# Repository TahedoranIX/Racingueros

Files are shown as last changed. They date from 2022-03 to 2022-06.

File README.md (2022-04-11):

# Racingueros
Todos los proyectos que vayamos haciendo a los coches.

## Proyectos
### [CuentaRevoluciones](https://github.com/TahedoranIX/Racingueros/tree/main/CuentaRevoluciones)
Cuentarevoluciones hecho con RPi zero W con pantalla lcd 16x2 y funciona mediante OBD.

## Estado de Proyectos
### Ideas

### En proceso

### Acabado
   **CuentaRevoluciones**

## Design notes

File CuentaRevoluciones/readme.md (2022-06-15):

# CuentaRevoluciones
Cuentarrevoluciones hecho con RPi zero W con pantalla lcd 16x2 y rotary-encoder. Funciona mediante OBDII.

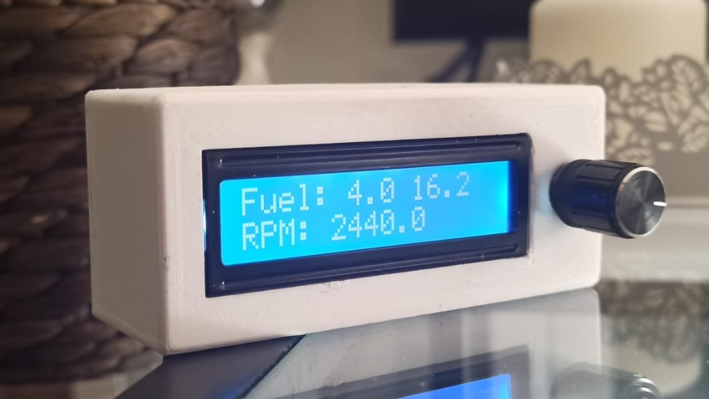
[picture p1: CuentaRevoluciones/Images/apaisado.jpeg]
CRR


### Objetivos
Mi Smart Fortwo solo tiene cuentarrevoluciones si lo pagas como un extra, el mío no vino con ese extra y no me apetece pagar más por él así que decidí hacerme uno utilizando el protocolo
 OBD-II.
La idea inicial es solo mostrar las revoluciones del motor pero como veréis, he implementado más cosas.
 
### Qué es? Cómo funciona?

Todo el programa esta escrito en Python3 y ejecutado en una RaspberryPi Zero W (versión con WiFi y Bluetooth).

La conexión al puerto OBD se realiza mediante Bluetooth y la librería python-OBD.

La pantalla utilizada es la típica LCD de 16x2 píxeles y adicionalmente utiliza un Rotary encoder para poder navegar entre distintos menús.

### Funciones Actuales
Actualmente el programa puede mostrar:
- RPM del motor.
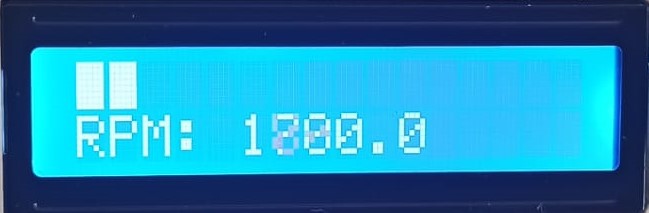
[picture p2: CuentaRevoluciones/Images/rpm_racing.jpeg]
RPM


- Temperatura del Refrigerante.
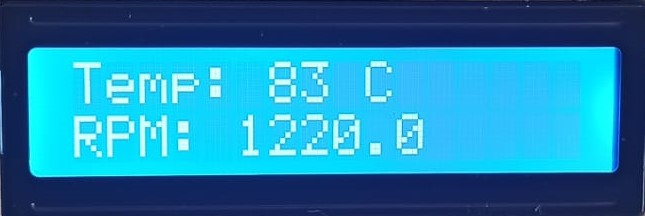
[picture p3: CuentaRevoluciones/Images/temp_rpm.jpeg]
Coolant Temp


- Consumo de gasolina (aproximado gracias al sensor MAF).
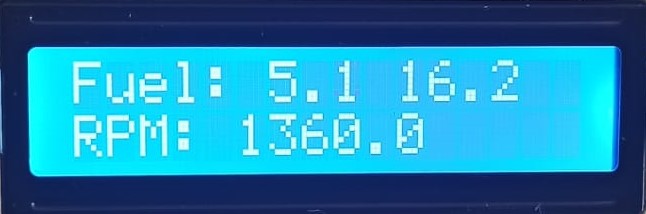
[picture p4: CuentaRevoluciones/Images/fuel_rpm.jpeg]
Fuel Cons.


- Tiempo de parada para cuidar el turbo.
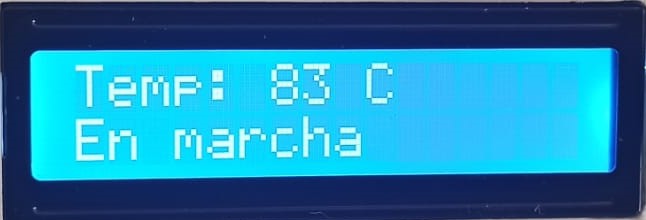
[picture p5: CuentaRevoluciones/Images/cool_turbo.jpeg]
Turbo Time


## Información Adicional

### Librerías

#### LCD Library
Librería para controlador **ST7066U** hecha por mí. Al ser más específica que la Adafruit funciona a mayor velocidad.

#### Rotary encoder Library
Le he realizado unos cambios para que funcione con el rotary conectado de GPIO -> GND y he añadido la función de un botón para los rotary con botón.

#### Modelos 3D
Modelos 3D en formato stl de la caja en carpeta **Modelos**

#### Conexiones:
Cableados a la RPi en carpeta **Images**

### Productos:
- [Librería OBD original](https://github.com/brendan-w/python-OBD)
- [Librería Rotary encoder original](https://github.com/nstansby/rpi-rotary-encoder-python)
- [Librería original LCD Adafruit](https://github.com/adafruit/Adafruit_Python_CharLCD)
- [Pantalla](https://es.aliexpress.com/item/32397063365.html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): LCD 1602
- [Obd](https://es.aliexpress.com/item/4000809053108.html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): elm327
- [Rotativo](https://es.aliexpress.com/item/4000028678187.html?gatewayAdapt=glo2esp&spm=a2g0o.9042311.0.0.274263c0LgHA3h)

### Enlaces de interés OBD:
Para programarlo todo, he utilizado un OBD-II virtual el cual te ahorra bastante tiempo, ya que no necesitas bajar directamente al coche.
- [OBD VIRTUAL](https://github.com/Ircama/ELM327-emulator)

OBD II Codes.
- [OBD PIDs](https://en.wikipedia.org/wiki/OBD-II_PIDs)

### Raspberry AP:
Este programa permite utilizar la Raspberry como punto de anclaje Wi-Fi y de esta manera poder meter actualizaciones 
sin necesidad de sacar la Rpi de la caja.
- [raspberry](https://www.raspberrypi.com/documentation/computers/configuration.html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)

### TODO:
#### IDEAS:
- Boton pulsado 10s, entra en modo debug y el wifi de la raspberry se enciende.

#### FASE PRUEBAS:
- Litros de combustible restantes en el tanque.

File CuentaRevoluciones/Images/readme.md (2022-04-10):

# Actual Pinout
Pinout specified in BCM Nomenclature.

## LCD:
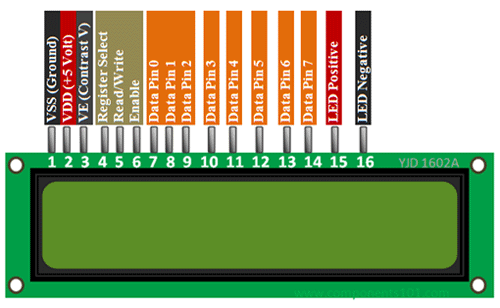
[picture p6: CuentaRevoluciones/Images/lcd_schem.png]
LCD


| |PIN |
|---|---|
|D7								|`GPIO 14` |
|D6								|`GPIO 15` |
|D5								|`GPIO 18`|
|D4								|`GPIO 23`|
|Enable								|`GPIO 24`|
|RegisterSelector								|`GPIO 25`|

## Rotary Encoder:
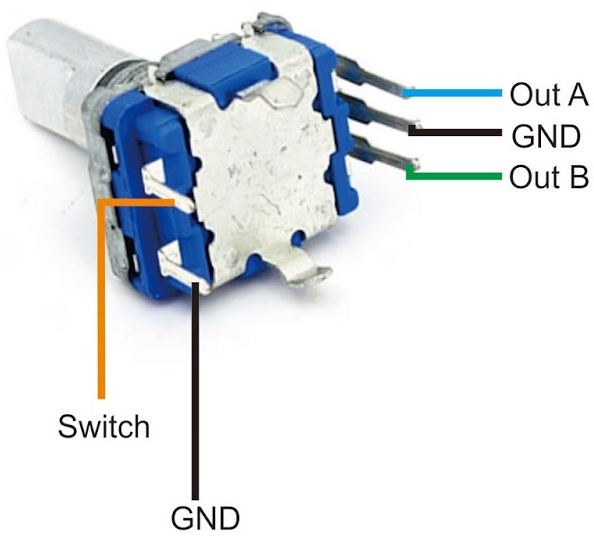
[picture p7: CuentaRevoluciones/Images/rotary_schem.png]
Rotary


| |PIN |
|---|---|
|OutA								|`GPIO 20`|
|OutB								|`GPIO 16`|
|Pulsar								|`GPIO 21`|

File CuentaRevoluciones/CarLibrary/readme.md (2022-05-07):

# Uso Básico de la Librería
Cada función está debidamente comentada, pero para no adentraros en código, resumo las funciones. 
Agradecer a mis amigos Raul y David por la ayuda en la toma de medidas del sensor MAF.

`Declaración: Smart(rs, en, d4, d5, d6, d7, port, e1, e2, eb, minimumSpeed)`

- `sos()`: Función de recuperación de errores. Util para meterlo dentro de un except.
- `startTurboCare(actualTime)`: Establece el inicio para realizar el descanso de un minuto en parado para refrigerar el turbo.
                                Recomendado ejecutarse en cada iteración y asi no depender de que menu nos encontramos.
- `turboCare(actualTime)`: Función menú que muestra el tiempo que queda de refrigeración de turbo y coolant temp. Depende de startTurboCare()
- `getStopped()`: Devuelve valor indicando si estamos parados o no.
- `getRotatory(menu)`: Pasando la cantidad de menus, comprueba si se ha girado el rotary y cambia a ese menu.
- `getButtonRotatory()`: Devuelve valor indicando si se ha pulsado el boton del rotary.
- `getOBDData()`: Función que obtiene todos los valores de OBD, se puede añadir cuantos se quieran, consultar python-OBD docs, para conocer todos los sensores.
- `fuelScreen()`: Función menu que muestra consumo instantáneo, promedio y las RPM.
- `rpmCoolScreen()`: Función menu que muestra RPM y Coolant temp.
- `rpmScreen()`: Función menu que muestra RPM y segments racing.

### Nota sobre cálculo de consumo de combustible
Debido a que la ECU del Smart no me deja acceder a los inyectores, he aproximado el consumo extrayendo los datos
del sensor MAF (sensor que indica el caudal de aire que entra en la admisión en gramos/segundo), a partir de ahí
he supuesto que la ECU hace los cálculos pertinentes para garantizar una mezcla estequiométrica y (mediante un sencillo factor de conversión)
he podido suponer la cantidad de combustible que se está inyectando en todo el motor.

Factor de Conversión

Finalmente he tenido en cuenta la posición del acelerador debido a que la mariposa
de admisión no se cierra por completo nunca y por tanto sin acelerar, había consumo.

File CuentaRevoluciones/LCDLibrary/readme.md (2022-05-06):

# Uso Básico de la Librería
Cada función está debidamente comentada, pero para no adentraros en código, resumo las funciones. 

`Declaración: LCD(d4, d5, d6, d7, en, rs)`

- `writeRAM(data=8bit array)`: Escribir directamente en la ram de escritura en pantalla, consultar datasheet para conocer los bits de cada char.
- `home()`: Devuelve cursor a inicio.
- `display(display="activa/desactiva pantalla", cursor="activa/desactiva vision del cursor", blink="activa/desactiva cursor blinking") 
  `: Función que configura el cursor, y la visión de la pantalla
- `moveCursor(direction="dirección a la que mover el cursor", times="veces que movemos el cursor") `: Mover cursor por la pantalla para posicionarnos.
- `clearDisplay() `: Limpia todos los chars de la pantalla, **importante** cada vez que queramos escribir en pantalla.
- `textLeftRight() `: Escritura de izquierda a derecha. (la buena)
- `textRightLeft() `: Escritura de derecha a izquierda.
- `writeMessage(string message) `: Llamada primordial para escribir chars en pantalla.

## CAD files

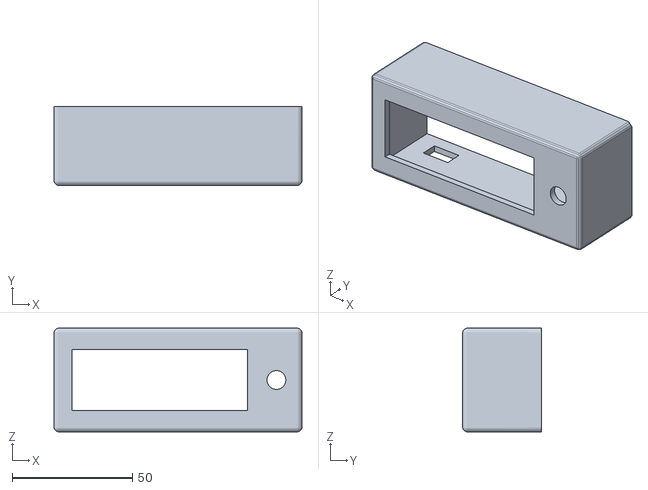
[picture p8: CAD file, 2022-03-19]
CuentaRevoluciones/Modelos/lcd_case.stl
103.0 x 32.7 x 43.0

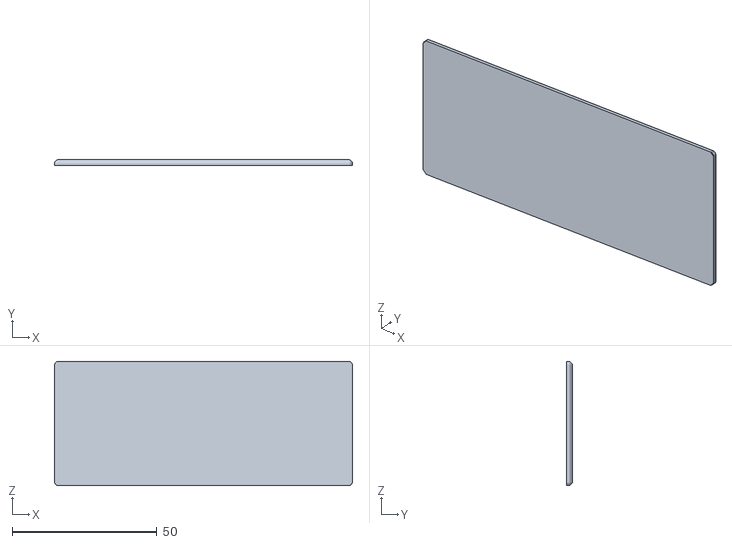
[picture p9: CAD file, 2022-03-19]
CuentaRevoluciones/Modelos/lcd_tapa.stl
103.0 x 2.00 x 43.0

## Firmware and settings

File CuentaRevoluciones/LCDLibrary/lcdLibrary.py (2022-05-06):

import RPi.GPIO as GPIO
from time import sleep
from Adafruit_CharLCD import Adafruit_CharLCD

LOW_TIME = 0.00004
HIGH_TIME = 0.00153
#LOW_TIME = 0.001
#HIGH_TIME = 1
GPIO.setwarnings(False)

class LCD:
    def __init__(self, d4, d5, d6, d7, en, rs):
        """Pin set and LCD init"""

        #######################
        # pin assignment
        #######################
        GPIO.setmode(GPIO.BCM)
        self.__datas = [d7,d6,d5,d4]
        self.__en = en
        self.__rs = rs
        for pin in (rs, en, d4, d5, d6, d7):
            GPIO.setup(pin, GPIO.OUT)

        #######################
        # begin INIT
        #######################

        #function set1
        self.__sendCommand(rs=0, data=[0,0,1,1,0,0,1,1], time=LOW_TIME)
        self.__sendCommand(rs=0, data=[0,0,1,1,0,0,1,0], time=LOW_TIME)
        #function set2
        self.__functionSet()
        #function set3
        self.__functionSet()
        #display on
        self.display()
        #clear
        self.clearDisplay()
        #entry mode
        self.__entryMode()
        #######################
        # end INIT
        #######################

    def __del__(self):
        self.clearDisplay()
        #GPIO.cleanup()

    def __enviar(self):
        ''' Trigger PIN ENABLE'''
        GPIO.output(self.__en, 0)
        GPIO.output(self.__en, 1)
        GPIO.output(self.__en, 0)

    def __sendCommand(self, rs, data, time):
        """
        SendCommand to LCD

        :param rs: Pin RS (instruction/data register)
        :param data: 8bit list data.
        :param time: HIGH_TIME/LOW_TIME
        """
        GPIO.output(self.__rs, rs)
        GPIO.output(self.__datas, data[:4])
        self.__enviar()
        GPIO.output(self.__datas, data[4:])
        self.__enviar()
        sleep(time)

    def __functionSet(self):
        """ Set bit mode LCD, only used in init"""
        self.__sendCommand(rs=0, data=[0,0,1,0,1,0,0,0], time=LOW_TIME)

    def __setCGRAM(self, address):
        """
        Set CGRAM address to AC (custom chars)

        :param address: 6bit Address(5-0)
        """
        self.__sendCommand(rs=0, data=[0,1,address[0],address[1],address[2],address[3],address[4],address[5]], time=LOW_TIME)

    def __setDDRAM(self, address):
        """
        Set DDRAM addresss to AC ('\ n' for example)

        :param address: 7bit Address(6-0)
        """
        self.__sendCommand(rs=0, data=[1,address[0],address[1],address[2],address[3],address[4],address[5],address[6]], time=LOW_TIME)

    def writeRAM(self, data):
        """
        Write data in RAM, show chars.

        :param data: 8bit data package.
        """
        self.__sendCommand(rs=1, data=data, time=LOW_TIME)

    def __entryMode(self,cursor=1,display=0):
        """
        Set moving direction of cursor and display.

        :param cursor: set orientation of cursor
        :param display: shift entire display
        """
        self.__sendCommand(rs=0, data=[0,0,0,0,0,1,cursor,display], time=LOW_TIME)

    def clearDisplay(self):
        """ Clear all display data"""
        self.__sendCommand(rs=0, data=[0,0,0,0,0,0,0,1], time=HIGH_TIME)
        
    def home(self):
        """ Return cursor to home"""
        self.__sendCommand(rs=0, data=[0,0,0,0,0,0,1,0], time=HIGH_TIME)

    def display(self, display=1, cursor=0, blink=0):
        """
        View options

        :param display: Show messages in display
        :param cursor: Show cursor
        :param blink: Show blinking cursor
        """
        self.__sendCommand(rs=0, data=[0,0,0,0,1,display,cursor,blink], time=LOW_TIME)

    def moveCursor(self, cursor=0, direction=1, times=1):
        """
        View options

        :param cursor: Shift cursor(0) display(1)
        :param direction: Direction right(1) left(0)
        :param times: Times to move
        """
        for i in range(times):
            self.__sendCommand(rs=0, data=[0,0,0,1,cursor,direction,0,0], time=LOW_TIME)
    
    def textLeftRight(self):
        """ Writes to the right (Normal)"""

        self.__sendCommand(rs=0, data=[0,0,0,0,0,1,1,0], time=LOW_TIME)
        
    def textRightLeft(self):
        """ Writes to the left ¿?"""
        self.__sendCommand(rs=0, data=[0,0,0,0,0,1,0,0], time=LOW_TIME)

    def writeMessage(self, message):
        """Write message in display """
        for char in message:
            if char == '\n':
                self.__setDDRAM([1,0,0,0,0,0,0])
            else:
                dataMessage = []
                letra = bin(ord(char))[2:].zfill(8)
                for binario in letra:
                    dataMessage.append(int(binario))
                self.writeRAM(dataMessage)

if __name__ == "__main__":
    h = LCD(d4=23,d5=18,d6=15,d7=14,en=24,rs=25)
    h.writeMessage("hola que tal\nyo bien")
    sleep(2)

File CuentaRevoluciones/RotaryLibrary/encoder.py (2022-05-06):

# Class to monitor a rotary encoder and update a value.  You can either read the value when you need it, by calling getValue(), or
# you can configure a callback which will be called whenever the value changes.

import RPi.GPIO as GPIO

class Encoder:

    def __init__(self, leftPin, rightPin, buttonPin, callback=None):
        self.leftPin = leftPin
        self.rightPin = rightPin
        self.buttonPin = buttonPin
        self.valueButton = 0
        self.value = 0
        self.state = '11'
        self.direction = None
        self.callback = callback
        GPIO.setup(self.leftPin, GPIO.IN, pull_up_down=GPIO.PUD_UP)
        GPIO.setup(self.rightPin, GPIO.IN, pull_up_down=GPIO.PUD_UP)
        GPIO.setup(self.buttonPin, GPIO.IN, pull_up_down=GPIO.PUD_UP)
        GPIO.add_event_detect(self.leftPin, GPIO.BOTH, callback=self.transitionOccurred)
        GPIO.add_event_detect(self.rightPin, GPIO.BOTH, callback=self.transitionOccurred)
        #GPIO.add_event_detect(self.buttonPin, GPIO.FALLING, callback=self.buttonPressed)

    def transitionOccurred(self, channel):
        p1 = GPIO.input(self.leftPin)
        p2 = GPIO.input(self.rightPin)
        newState = "{}{}".format(p1, p2)
        if self.state == "00": # Resting position
            if newState == "01": # Turned right 1
                self.direction = "R"
            elif newState == "10": # Turned left 1
                self.direction = "L"

        elif self.state == "01": # R1 or L3 position
            if newState == "11": # Turned right 1
                self.direction = "R"
            elif newState == "00": # Turned left 1
                if self.direction == "L":
                    self.value = self.value - 1
                    if self.callback is not None:
                        self.callback(self.value, self.direction)

        elif self.state == "10": # R3 or L1
            if newState == "11": # Turned left 1
                self.direction = "L"
            elif newState == "00": # Turned right 1
                if self.direction == "R":
                    self.value = self.value + 1
                    if self.callback is not None:
                        self.callback(self.value, self.direction)

        else: # self.state == "11"
            if newState == "01": # Turned left 1
                self.direction = "L"
            elif newState == "10": # Turned right 1
                self.direction = "R"
            elif newState == "00": # Skipped an intermediate 01 or 10 state, but if we know direction then a turn is complete
                if self.direction == "L":
                    self.value = self.value - 1
                    if self.callback is not None:
                        self.callback(self.value, self.direction)
                elif self.direction == "R":
                    self.value = self.value + 1
                    if self.callback is not None:
                        self.callback(self.value, self.direction)

        self.state = newState

    #def buttonPressed(self, channel):
    #    self.valueButton = not self.valueButton


    def getValue(self):
        return self.value

    def getButtonValue(self):
        return not GPIO.input(self.buttonPin)

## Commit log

2022-03-19 Primera Version Completamente Funcional
    [lcd_case.stl, lcd_tapa.stl]
2022-04-10 button encoder
2022-05-06 v1.0 consumo, encoder cambiado valor inicial a 11.
